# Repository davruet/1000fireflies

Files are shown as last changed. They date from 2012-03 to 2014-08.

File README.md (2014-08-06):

The Kuramoto Model (1000 Fireflies)
==================================

http://1000fireflies.net

The Kuramoto Model is a public art event. Organizers recruit cyclists and deploy masses of custom bike lights containing radio devices that communicate and synchronize blinks with one another.

This is a community-based public art project that uses custom-made bike lights to create an interactive event on the scale of a city. LED lights designed and made by Chicago-based artist David Rueter are outfitted with electronics that allow them to communicate with others of their kind and automatically synchronize their blinks, forming a self-organizing system. Individually, these devices appear similar to conventional cycling safety lights, but in groups, they exhibit an immediately noticeable and striking phenomenon of unified flashing.

This September, the project received an Honorary Mention in Interactive Art for the Prix Ars Electronica in Linz, Austria. In 2012, NorthernLights.mn presented The Kuramoto Model in Minneapolis as part of the Northern Spark all-night arts festival.

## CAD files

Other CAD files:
hardware/NorthernSpark2012/acrylic_box/box_2d.3dm
hardware/NorthernSpark2012/acrylic_box/box_2d_1.4inch.3dm

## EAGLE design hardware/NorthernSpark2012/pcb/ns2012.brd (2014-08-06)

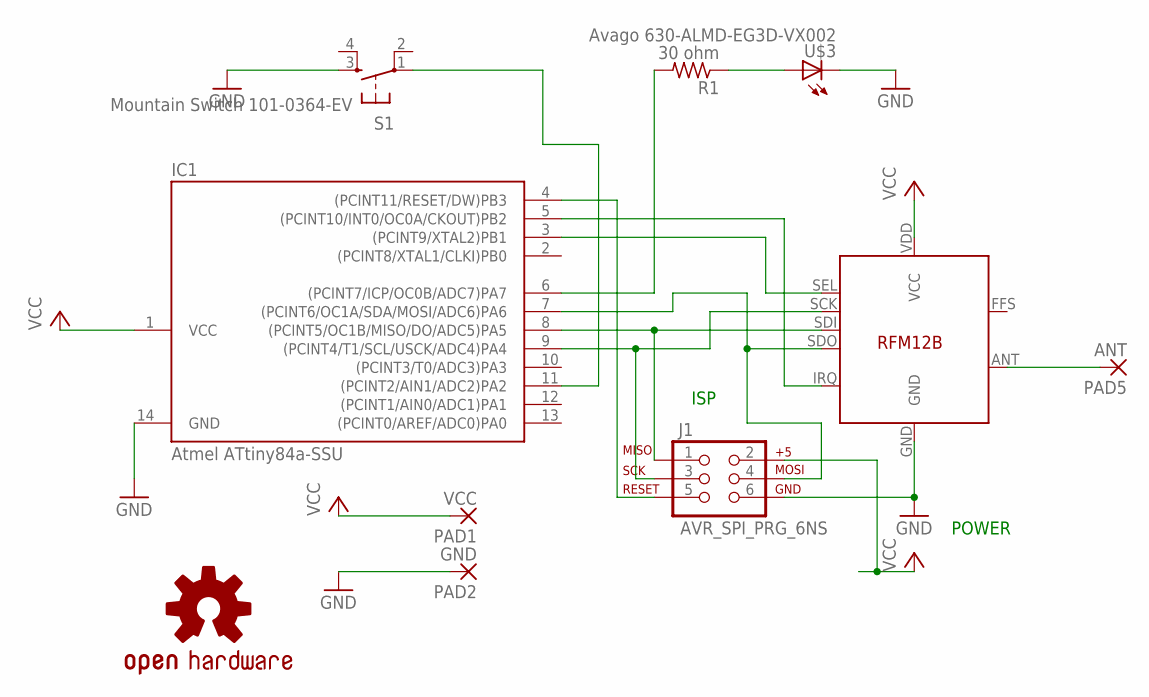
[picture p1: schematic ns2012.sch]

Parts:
IC1: Atmel ATtiny84a-SSU; SOIC14
J1: AVR_SPI_PRG_6NS; 2X3-NS
PAD1: VCC; 2,15/1,0
PAD2: GND; 2,15/1,0
PAD5: ANT; 2,15/1,0
R1: 30 ohm; R0805
RFM12B: HopeRF RFM12B-433S1; RFM12B-NARROW
S1: Mountain Switch 101-0364-EV; DTSM-6
U$1: OSHW-LOGOS; OSHW-LOGO-S
U$3: Avago 630-ALMD-EG3D-VX002; ALMD-**3D

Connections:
GND: IC1.14 (GND), J1.6, PAD2.1, RFM12B.GND, S1.3, U$3.C1 (C), U$3.C2 (C)
unnamed: R1.1, U$3.A1 (A), U$3.A2 (A)
unnamed: IC1.9 ((PCINT4/T1/SCL/USCK/ADC4)PA4), J1.3, RFM12B.SCK
unnamed: IC1.8 ((PCINT5/OC1B/MISO/DO/ADC5)PA5), J1.1, RFM12B.SDI
unnamed: IC1.7 ((PCINT6/OC1A/SDA/MOSI/ADC6)PA6), J1.4, RFM12B.SDO
unnamed: IC1.3 ((PCINT9/XTAL2)PB1), RFM12B.SEL
unnamed: IC1.6 ((PCINT7/ICP/OC0B/ADC7)PA7), R1.2
unnamed: IC1.5 ((PCINT10/INT0/OC0A/CKOUT)PB2), RFM12B.IRQ
unnamed: PAD5.1, RFM12B.ANT
unnamed: IC1.11 ((PCINT2/AIN1/ADC2)PA2), S1.1
unnamed: IC1.4 ((PCINT11/RESET/DW)PB3), J1.5
VCC: IC1.1 (VCC), J1.2, PAD1.1, RFM12B.VDD (VCC)

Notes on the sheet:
ISP
POWER

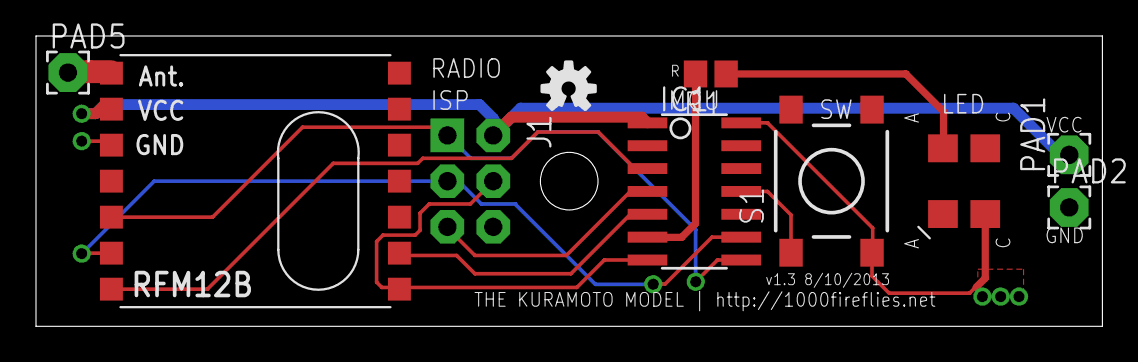
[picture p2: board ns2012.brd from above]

Board: 2 copper layers, 59.2 x 16.1 mm, 10 parts (0 on the bottom side), 12 nets.

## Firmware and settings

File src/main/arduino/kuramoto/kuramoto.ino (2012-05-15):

/*
  THE KURAMOTO MODEL
  
*/
 
#include <Ports.h>
#include <RF12.h>
#include <avr/sleep.h>
#include <avr/wdt.h>
#include <math.h>

#ifndef cbi
#define cbi(sfr, bit) (_SFR_BYTE(sfr) &= ~_BV(bit))
#endif
#ifndef sbi
#define sbi(sfr, bit) (_SFR_BYTE(sfr) |= _BV(bit))  
#endif

#define LED_PIN 3
#define SWITCH_PIN 8

#define RF12_SLEEP 0
#define RF12_WAKEUP -1

#define INITIAL_SYNC_PERIOD 1000000 // Duration in microseconds of the blink cycle
#define PERIOD_TOLERANCE (INITIAL_SYNC_PERIOD / 10)

//#define ALONE_PERIOD 300000
//#define HALF_PERIOD 500000 
#define LED_DURATION 70000 // Duration in microseconds of the LED blink
#define PHASE_SHIFT_FACTOR 10 // Strength coefficient of adjustment made when receiving other signals
#define PERIOD_CHANGE_FACTOR 40
#define SEND_FAIL_LIMIT 20
#define MAX_CORRECTION INITIAL_SYNC_PERIOD / 5

unsigned int payload = 5;
unsigned long int period = INITIAL_SYNC_PERIOD;

struct filter {
  unsigned long int current;
  unsigned long int sum;
  unsigned long int filtered;
};

unsigned long ledTriggerTime = 0;
unsigned long lastReportTime = 0;

boolean ledOn = false;

int consecutiveSendFailures = 0;


filter peers;
//filter coherence;



//power button variables
unsigned int buttonState = 0;
boolean waitingForSleep = false;
boolean buttonIsDown = false;
boolean shutdownEnabled = false;

void rampUpLED(){ 
   for (int j = 0; j <= 255; j++){
      analogWrite(LED_PIN, j);
      delay(2);
    }  
}

void rampDownLED(){
   for (int j = 255; j >= 0; j--){
      analogWrite(LED_PIN, j);
      delay(2);
    }  
    

}

void startupBlinks(){
  for (int i = 0; i< 3; i++){
    rampUpLED();
    rampDownLED();
  }
 
}
void setup() {     
  MCUSR = 0;
  wdt_enable(WDTO_8S); // enable the watchdog - for safety!
  pinMode(SWITCH_PIN,INPUT);
  digitalWrite(SWITCH_PIN, HIGH);
  sbi(GIMSK,PCIE0); // Enable PCI
  sbi(PCMSK0,PCINT2); // Set PCInt2 as the PCI pin  

  pinMode(LED_PIN, OUTPUT);  
  


  rf12_initialize(4, RF12_433MHZ, 20);
  rf12_control(0xC040); // low battery detect set to 2.1
  startupBlinks();
  ledTriggerTime = micros();

}

/** Gets the raw (un-debounced) value from the button.
Returns 1 if button is pressed, 0 otherwise. **/
unsigned int getRawButtonValue(){
  return digitalRead( SWITCH_PIN) == LOW;
}

/** Non-standard things to do before sleeping (e.g. shut off peripherals, etc.)
*/
void getReadyForBed(){
  waitingForSleep = false;
  rampDownLED();
  rf12_sleep(RF12_SLEEP);
  digitalWrite(LED_PIN, LOW);
  MCUSR = 0;
  wdt_disable();
}

/** Non-standard things to do after awakening (e.g. turn on peripherals, etc.)
*/
void startTheDay(){
  
  reboot(); // do a reset
  //rf12_sleep(RF12_WAKEUP);

  //digitalWrite(SWITCH_PIN, HIGH);
  //digitalWrite(LED_PIN, HIGH);
}

void reboot(){
  MCUSR = 0;
  wdt_enable(WDTO_15MS);
  for (;;){} // INFINNITE LOOP, causes watchdog restart.
}


void goToSleep() {
  getReadyForBed();
  cbi(ADCSRA,ADEN); // Turn off ADC
 
  set_sleep_mode(SLEEP_MODE_PWR_DOWN); // Go to sleep
  sleep_mode(); // Sleep starts after this line
  //sleep_cpu();

  sbi(ADCSRA,ADEN);  // Turn on ADC
  startTheDay();
}

void checkPowerToggle(){
  unsigned int currentValue = getRawButtonValue();
  buttonState <<= 1;
  buttonState |= currentValue;
  
  buttonIsDown = (buttonState == 0xffff);
  shutdownEnabled = shutdownEnabled | (buttonState == 0); 
  if (buttonIsDown && shutdownEnabled){
    waitingForSleep = true;
    
  } else {
    
    if (waitingForSleep){
      shutdownEnabled = false;
      waitingForSleep = false;
      goToSleep();
      
      shutdownEnabled = false;
      waitingForSleep = false;
    } 
  }  
}


unsigned long getPhase(){
    unsigned long now = micros();
    if (now < ledTriggerTime) return 0;
    unsigned long phase = now - ledTriggerTime;
    return phase;
}

boolean listen(){
  boolean received = rf12_recvDone() && rf12_crc == 0 && rf12_len == sizeof payload;  //-disable CRC and len check - noise is ok.
  if (received) lastReportTime = micros();
  return received;
  //return rf12_recvDone();
  //return false;
}

 boolean broadcast(){
    boolean canSend = rf12_canSend();
    if (canSend){
      rf12_sendStart(0, &payload, sizeof payload);
      consecutiveSendFailures = 0;
    }
    else {
      consecutiveSendFailures++;  
    }
    return canSend;
}

void updateFilter(struct filter *value, unsigned int sampleCount){
  value->sum += value->current - value->filtered;
  value->filtered = value->sum / sampleCount;
  value->current = 0;
}



void loop() {
  checkPowerToggle();
  
   /*if (micros() - lastReportTime > 5000000) period = ALONE_PERIOD;
   else period = SYNC_PERIOD;
  */
  if (listen()) {
    //p("pulse %i avg %i val %i\n ", irDiff, irFilteredValue, val);
    unsigned long timediff = micros() - ledTriggerTime;
    long adjustment;
    if (timediff < period / 2){ // we are too early. 
      adjustment = (long)timediff;
      //p("early %li +- %li\n", timediff, adjustment);
     } else { // we are too late
      adjustment = ((long)timediff - (long)period);
      //p("late %li +- %li\n", timediff, adjustment);
    }
    
    peers.current++;
    //coherence.current += abs(adjustment);
    
    adjustment /= PHASE_SHIFT_FACTOR;
    adjustment /= max(1, (int)peers.filtered); // scale the adjustment by a shift factor weighted by peer count
    adjustment = constrain(adjustment, -MAX_CORRECTION, MAX_CORRECTION);
    
    ledTriggerTime += adjustment;  
    
    period += adjustment / PERIOD_CHANGE_FACTOR;
    period = constrain(period, INITIAL_SYNC_PERIOD - PERIOD_TOLERANCE, INITIAL_SYNC_PERIOD + PERIOD_TOLERANCE);

  }
  
  unsigned long phase = getPhase();
  
  if (!ledOn && phase > period){
    // phase is done.
    if (consecutiveSendFailures < SEND_FAIL_LIMIT) wdt_reset(); // reset the watchdog only when we turn on the led and reset the timer.
    ledOn = true;
    digitalWrite(LED_PIN, HIGH);

    
    ledTriggerTime = micros();
    broadcast();// Transmit a radio beacon.
    phase = getPhase();
     
    //reset the peer count
    updateFilter(&peers, 10);
     
    //updateFilter(&coherence, 3);
    //unsigned int normalizedCoherence = (unsigned int)(coherence.filtered / (1 + peers.filtered * 1000));
    
    payload = peers.filtered;
     

  } 

  if (ledOn && phase > LED_DURATION){
    ledOn = false;
    //analogWrite(LED_PIN, 0);
    digitalWrite(LED_PIN, LOW);
  }
  
}




ISR(PCINT0_vect) {} //no-op interrupt

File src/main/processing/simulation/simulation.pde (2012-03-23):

import toxi.geom.Vec2D;
import toxi.geom.Rect;
import toxi.geom.PointQuadtree;
import java.util.HashMap;
import toxi.color.TColor;
import processing.video.*;
import controlP5.*;

int count = 1000;
static int ON_THRESHOLD = 700;
static int ON_DURATION = 100;
static int PHASE_THRESHOLD = ON_THRESHOLD + ON_DURATION;
static int ADJUSTMENT_MAX = ON_THRESHOLD / 2;

int radius = 320  ;
int syncMultiple = 75;

float timefactor = 1.0;

ArrayList<Vec2D> cyclists = new ArrayList<Vec2D>(count);
long lastTimeAdded;
long loopBegin;
ControlP5 controlP5;
MovieMaker mm;

void setup(){
  
  size(1280, 720);
  controlP5 = new ControlP5(this);
  controlP5.addSlider("radius", 0, 500);
  controlP5.addSlider("syncMultiple", 0, 100);
  controlP5.addSlider("timefactor", 1.0, 5.0);
  controlP5.hide();
   //
   
}


void update(){
  
  if (millis() > lastTimeAdded + 300 && cyclists.size() < 300){
    Cyclist c = new Cyclist();
    c.set(random(width), random(height));
    cyclists.add(c);
    lastTimeAdded = millis();
  }
  
  for (int i = 0; i< cyclists.size(); i++){
    Cyclist c = (Cyclist)cyclists.get(i);  
    c.update();
    
    
  }
  
  
  PointQuadtree tree = new PointQuadtree(new Vec2D(-1,-1), 1280);
  tree.addAll(cyclists);
  for (int i = 0; i< cyclists.size(); i++){
    Cyclist c = (Cyclist)cyclists.get(i);
    if (c.isActive()){
      Rect rect = new Rect(c.x() - radius / 2, c.y - radius / 2, radius, radius);
      ArrayList<Vec2D> neighbors = tree.getPointsWithinRect(rect);
      if (neighbors != null){
        for (Vec2D neighborV : neighbors){
          Cyclist neighbor = (Cyclist)neighborV;
          neighbor.pulse();
        }
      }  
    }
  }
  
}

TColor light = TColor.newRGB(255,0,0);

void draw(){
  loopBegin = millis();
  update();
  background(0, 0, 25);
  
  for (int i = 0; i< cyclists.size(); i++){
    Cyclist c = (Cyclist)cyclists.get(i); 
    TColor col = TColor.newRGB(.1,.1,.2);
    if (c.isActive()){
       col.blend(light, c.getIntensity());
      fill(col.toARGB());
      if (c.getIntensity() > 1 || c.getIntensity() < 0) println(c.getIntensity());
      //fill(255);
    }
    else fill(col.toARGB());
    ellipse(c.x(), c.y(), 10, 10);
  }
  // throttle
  //delay((int)Math.max(0, 5 - (millis() - loopBegin)));
  if (mm != null) mm.addFrame();
}


class Cyclist extends Vec2D {
  float intensity = random(PHASE_THRESHOLD);  
  int phaseAdjustment = 0;
   
   
  Vec2D velocity = new Vec2D();
  
  void update(){
    /*velocity = velocity.add( (noise(position.x(), position.y(), millis()/10f) - .5) ,
                  (noise(position.x(), position.y(), millis()/10f) - .5));*/
                  
    velocity = velocity.jitter(.01);
    this.addSelf(velocity);
    if (this.x() < 0 || this.x() > width) {
      velocity = velocity.scale(-1,1);
    }
    if (this.y() < 0 || this.y() > height) {
      velocity = velocity.scale(1,-1);
    }
    
    velocity = velocity.scale(.999);
    
    
    intensity+= 10 * timefactor;
    if (intensity >= PHASE_THRESHOLD){
      intensity = 0;
      phaseAdjustment = 0;
    }
  }
  
  void pulse(){
    // if already on, don't listen for pulses, increment normally.
    if (isActive()) return;
    float increment = 0;
    if (intensity < ON_THRESHOLD / 2){
      increment = -1 * Math.max(0, intensity) / syncMultiple;     
    } else {
      increment = ON_THRESHOLD - Math.min(ON_THRESHOLD, intensity) / syncMultiple;
    }
    phaseAdjustment += increment * timefactor;
    if (phaseAdjustment > -ADJUSTMENT_MAX && phaseAdjustment < ADJUSTMENT_MAX){
      intensity += increment;  
    }
    
  }
  
  boolean isActive(){
    return intensity > ON_THRESHOLD; 
  }
  
  float getIntensity(){
    
    return Math.max(0, ((float)ON_DURATION - (intensity - ON_THRESHOLD)) / ON_DURATION); 
  }
  
}
int movieId = 0;

void keyPressed(){
  switch (key){
     case ' ':
      if (controlP5.isVisible()) controlP5.hide();
      else controlP5.show();
      break;
     case 'r':
       if (mm == null){
         mm = new MovieMaker(this, width, height, "cycling" + movieId++ + ".mov",
                       30, MovieMaker.ANIMATION, MovieMaker.BEST);
         timefactor = 2;
       } else {
         mm.finish();
         mm = null;
         timefactor = 1;
       }
                       
  }
 // mm.finish();  
}

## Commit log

2012-04-02 Added Eagle PCB files, plus gerber output
    [kuramoto5.brd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]
2012-04-03 Fixed bug with RF12 coms
    [kuramoto.ino]
2012-04-03 Integrated power button code
2012-04-05 Added first rev of box. TODO - enlarge size for 1.4" PCB
    [box_2d.3dm]
2012-04-19 Re-tooled board with 12 mil traces, fewer vias, ground plane, and prettier looks. Moved problematic vias that were too close to pads. Removed unused photoresistor and resistor.
    [kuramoto6.brd, kuramoto6.sch]
2012-04-19 Memory tweaks, button debouncing, refactoring.
2012-04-19 Added Rhino model for acrylic housing.
    [box_2d_1.4inch.3dm]
2012-04-20 Board redesign, smaller and better vias. Enough room for RFM12B. This rev was submitted to Gold Phoenix PCB for a quote, DARU033475CAQ
    [kuramoto7.brd, kuramoto7.sch]
2012-05-01 Added startup sequence blinking, shortened cycle time, added reboot on radio failure
    [kuramoto.ino]
2014-08-06 Removed old revisions and added two new ones. General repo cleanup.
    [box_2d.3dm, box_2d_1.4inch.3dm, chi2013.brd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]

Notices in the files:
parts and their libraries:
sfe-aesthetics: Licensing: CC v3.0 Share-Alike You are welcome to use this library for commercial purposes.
